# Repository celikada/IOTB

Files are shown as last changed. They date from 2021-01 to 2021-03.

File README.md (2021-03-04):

# IOTB
### Internet of Things Device
#### Version 3.0: 2021-1-17 [Wiki](https://github.com/celikada/IOTB/wiki)

#### Get expedited support or integration consultation for IOTB [from IOTECH](http://iotech.com.tr/)

IOTECH (http://iotech.com.tr)
---

IOTECH (http://iotech.com.tr)
### OVERVIEW:
IOTB is an internet of things edge device implementation. The hardware has digital inputs and outputs and offers connectivity for analog sensors and extensions.
It has open source firmware and upload ready various tcp/ip connection options according to needs.

**It is a platform**

IOTB is a platform that users can create and upload a firmware which they needed. 

**Main features:**
1. 100Mb Ethernet.
2. TTL Serial connection.
3. 8 Digital Inputs.
4. 8 Digital Outputs.
5. 5V-26V operational power range.
6. Opto isolation for IO.
7. 2 line (4+4) Isolated input voltage. 
8. Isolaated Output voltage.
9. Current protection for outputs.
10. Voltage progection for outputs.

IOTECH (http://iotech.com.tr)
IOTECH (http://iotech.com.tr)
IOTECH (http://iotech.com.tr)

STM32 architectute. Modbus and MQTT ready software.

### Changelog is located [here.](https://github.com/celikada/IOTB/wiki/Changelog)

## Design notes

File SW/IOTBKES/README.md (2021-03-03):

### IOTB Plant Firmware
 Various sensors and IO implementation for plants growing and ThingSpeak comminication.

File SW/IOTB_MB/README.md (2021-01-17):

# IOTB MODBUS
### IOTB Modbus Communication Software
#### Version 3.0: 2021-1-17 [Wiki](https://github.com/celikada/IOTB/wiki)

#### Get expedited support or integration consultation for IOTB [from IOTECH](http://iotech.com.tr/)

IOTECH (http://iotech.com.tr)
---

### OVERVIEW:
IOTB is an internet of things edge device implementation. The hardware has digital inputs and outputs and offers connectivity for analog sensors and extensions.
It has open source firmware and upload ready various tcp/ip connection options according to needs.

#### Register Address ####

**Holding Register**

1. Status
2. Version
3. SerialNum
4. IP1
5. IP2
6. IP3
7. IP4
8. MASK1
9. MASK2
10. MASK3
11. MASK4
12. GW1
13. GW2
14. GW3
15. GW4
16. DNS1
17. DNS2
18. DNS3
19. DNS4
20. IPS1
21. IPS2
22. IPS3
23. IPS4
24. CommPortH
25. CommPortL
26. VolatileOut
27. Reset

**Input Registers**

1. IN1
2. IN2
3. IN3
4. IN4
5. IN5
6. IN6
7. IN7
8. IN8
9. OUTPUTS
10. sht31 Temp
11. sht31 Hum
12. Board Temp
13. reserved
14. reserved

**Coil Registers**

1. OUT1
2. OUT2
3. OUT3
4. OUT4
5. OUT5
6. OUT6
7. OUT7
8. OUT8

Changelog is located here.

### Changelog is located [here.](https://github.com/celikada/IOTB/wiki/Changelog)

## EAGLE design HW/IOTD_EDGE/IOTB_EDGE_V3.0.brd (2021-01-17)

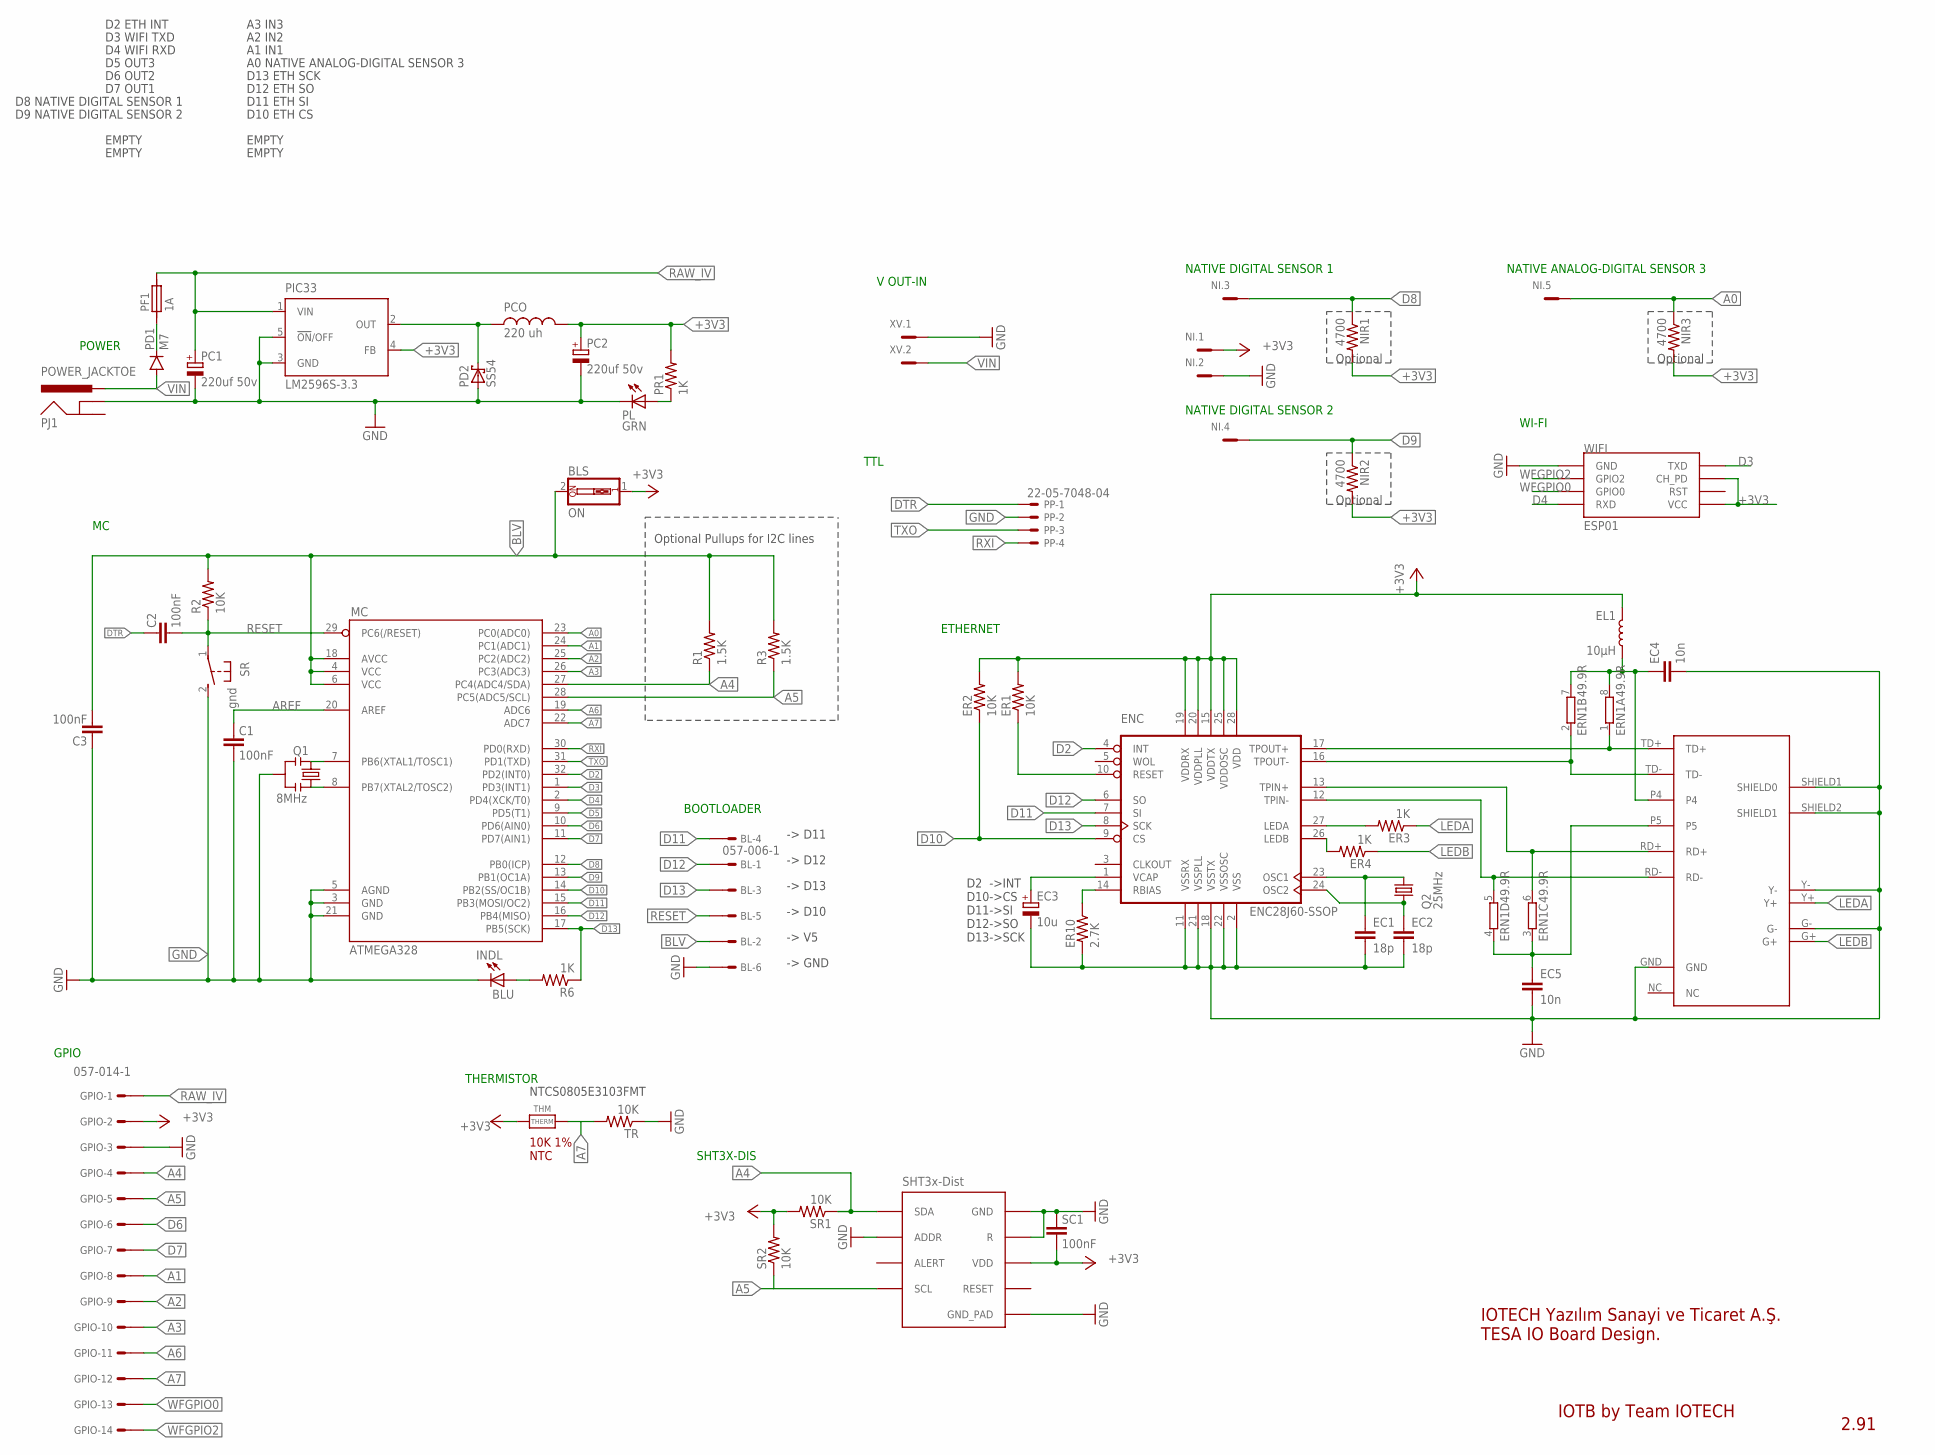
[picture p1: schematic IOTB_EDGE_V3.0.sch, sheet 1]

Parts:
BL: 057-006-1
BLS: ON; EDG-01
C1, C2, C3: 100nF; 0805
EC1, EC2: 18p; 0805
EC3: 10u; CT3216
EC4, EC5: 10n; 0805
EL1: 10µH; 0805
ENC: ENC28J60-SSOP; SSOP28
ER1, ER2: 10K; 0805
ER3, ER4: 1K; 0805
ER10: 2.7K; 0805
ERN1: 49.9R; 0603-ARV
ETHSOC: HR911105A; RJ45
GPIO: 057-014-1
INDL: BLU; CHIP-LED0805
MC: ATMEGA328; TQFP32-08
NI: MC5
NIR1, NIR2, NIR3: 4700; 0805
PC1, PC2: 220uf 50v; 140CLH-1010
PCO: 220 uh; MSS1260
PD1: M7; SMA-DIODE
PD2: SS54; SMB
PF1: 1A; 1820
PIC33: LM2596S-3.3; TO263-5
PJ1: POWER_JACKTOE; POWER_JACK_SMD_OVERPASTE_TOE
PL: GRN; CHIP-LED0805
PP: 22-05-7048-04; 7395-04
PR1: 1K; 0805
Q1: 8MHz; RESONATOR-SMD-1:1
Q2: 25MHz; 5.0X3.2_2
R1, R3: 1.5K; 0805
R2: 10K; 0805
R6: 1K; 0805
SC1: 100nF; 0805
SHT: SHT3X
SR: gnd; B3F-31XX
SR1, SR2: 10K; 0805
THM: THERM; MICROBUILDER_0805_NOTHERMALS
TR: 10K; 0805
WIFI: ESP01
XV: MC2

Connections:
+3V3: BLS.1, EL1.1, ENC.15 (VDDTX), ENC.19 (VDDRX), ENC.20 (VDDPLL), ENC.25 (VDDOSC), ENC.28 (VDD), ER1.2, ER2.2, GPIO.2, NI.1, NIR1.2, NIR2.2, NIR3.2, PC2.+, PCO.P$1, PIC33.4 (FB), PR1.2, SC1.1, SHT.VDD, SR1.2, SR2.2, THM.1, WIFI.CH_PD, WIFI.VCC; also elsewhere on the board
A0: MC.23 (PC0(ADC0)), NI.5, NIR3.1
A1: GPIO.8, MC.24 (PC1(ADC1))
A2: GPIO.9, MC.25 (PC2(ADC2))
A3: GPIO.10, MC.26 (PC3(ADC3))
A4: GPIO.4, MC.27 (PC4(ADC4/SDA)), R1.1, SHT.SDA, SR1.1; also elsewhere on the board
A5: GPIO.5, MC.28 (PC5(ADC5/SCL)), R3.1, SHT.SCL, SR2.1; also elsewhere on the board
A6: GPIO.11, MC.19 (ADC6)
A7: GPIO.12, MC.22 (ADC7), THM.2, TR.2
AREF: C1.2, MC.20 (AREF)
BLV: BL.2, BLS.2, C3.1, MC.4 (VCC), MC.6 (VCC), MC.18 (AVCC), R1.2, R2.2, R3.2
D2: ENC.4 (INT), MC.32 (PD2(INT0))
D3: MC.1 (PD3(INT1)), WIFI.TX (TXD)
D4: MC.2 (PD4(XCK/T0)), WIFI.RX (RXD)
D5: MC.9 (PD5(T1)); also elsewhere on the board
D6: GPIO.6, MC.10 (PD6(AIN0))
D7: GPIO.7, MC.11 (PD7(AIN1))
D8: MC.12 (PB0(ICP)), NI.3, NIR1.1
D9: MC.13 (PB1(OC1A)), NI.4, NIR2.1
D10: ENC.9 (CS), ER2.1, MC.14 (PB2(SS/OC1B))
D11: BL.4, ENC.7 (SI), MC.15 (PB3(MOSI/OC2))
D12: BL.1, ENC.6 (SO), MC.16 (PB4(MISO))
D13: BL.3, ENC.8 (SCK), MC.17 (PB5(SCK)), R6.1
DTR: C2.2, PP.1
EP4: EC4.1, EL1.2, ERN1.7 (2), ERN1.8 (2), ETHSOC.P4
EP5: EC5.1, ERN1.3 (1), ERN1.4 (1), ETHSOC.P5
GND: BL.6, C1.1, C3.2, EC1.2, EC2.2, EC3.-, EC4.2, EC5.2, ENC.2 (VSS), ENC.11 (VSSRX), ENC.18 (VSSTX), ENC.21 (VSSPLL), ENC.22 (VSSOSC), ER10.2, ETHSOC.G-, ETHSOC.GND, ETHSOC.SHIELD1 (SHIELD0), ETHSOC.SHIELD2 (SHIELD1), ETHSOC.Y-, GPIO.3, INDL.C, MC.3 (GND), MC.5 (AGND), MC.21 (GND), NI.2, PC1.-, PC2.-, PD2.A, PIC33.3 (GND), PIC33.5 (!ON!/OFF), PJ1.GND (GNDBREAK), PL.C, PP.2, Q1.2, SC1.2, SHT.ADDR, SHT.GND, SHT.GND_PAD, SHT.R, SR.2 (S), TR.1, WIFI.GND, XV.1; also elsewhere on the board
LEDA: ER3.1, ETHSOC.Y+
LEDB: ER4.1, ETHSOC.G+
unnamed: PD1.C, PF1.1
unnamed: INDL.A, R6.2
unnamed: ENC.27 (LEDA), ER3.2
unnamed: MC.8 (PB7(XTAL2/TOSC2)), Q1.3
unnamed: PL.A, PR1.1
unnamed: EC3.+, ENC.1 (VCAP)
unnamed: ENC.26 (LEDB), ER4.2
unnamed: MC.7 (PB6(XTAL1/TOSC1)), Q1.1
unnamed: PCO.P$2, PD2.C, PIC33.2 (OUT)
unnamed: ENC.10 (RESET), ER1.1
unnamed: ENC.14 (RBIAS), ER10.1
unnamed: EC2.1, ENC.24 (OSC2), Q2.1
unnamed: EC1.1, ENC.23 (OSC1), Q2.2
RAW_IV: GPIO.1, PC1.+, PF1.2, PIC33.1 (VIN)
RD+: ENC.13 (TPIN+), ERN1.6 (2), ETHSOC.RD+
RD-: ENC.12 (TPIN-), ERN1.5 (2), ETHSOC.RD-
RESET: BL.5, C2.1, MC.29 (PC6(/RESET)), R2.1, SR.1
RXI: MC.30 (PD0(RXD)), PP.4
TD+: ENC.17 (TPOUT+), ERN1.1, ETHSOC.TD+
TD-: ENC.16 (TPOUT-), ERN1.2 (1), ETHSOC.TD-
TXO: MC.31 (PD1(TXD)), PP.3
VIN: PD1.A, PJ1.VIN0 (PWR), XV.2
WFGPIO0: GPIO.13, WIFI.GPIO0
WFGPIO2: GPIO.14, WIFI.GPIO2

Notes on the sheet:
POWER
NATIVE DIGITAL SENSOR 1
NATIVE DIGITAL SENSOR 2
WI-FI
NATIVE ANALOG-DIGITAL SENSOR 3
IOTB by Team IOTECH
2.91
ETHERNET
D2 ->INT D10->CS D11->SI D12->SO D13->SCK
TTL
IOTECH Yazılım Sanayi ve Ticaret A.Ş. TESA IO Board Design.
Optional Pullups for I2C lines
D2 ETH INT
D8 NATIVE DIGITAL SENSOR 1
D9 NATIVE DIGITAL SENSOR 2
EMPTY
A3 IN3
A2 IN2
A1 IN1
A0 NATIVE ANALOG-DIGITAL SENSOR 3
D13 ETH SCK
D12 ETH SO
D11 ETH SI
D10 ETH CS
D4 WIFI RXD
D3 WIFI TXD
D7 OUT1
D6 OUT2
D5 OUT3
BOOTLOADER
-> D11
-> D12
-> D13
-> D10
-> V5
-> GND
Optional
V OUT-IN
GPIO
NTCS0805E3103FMT

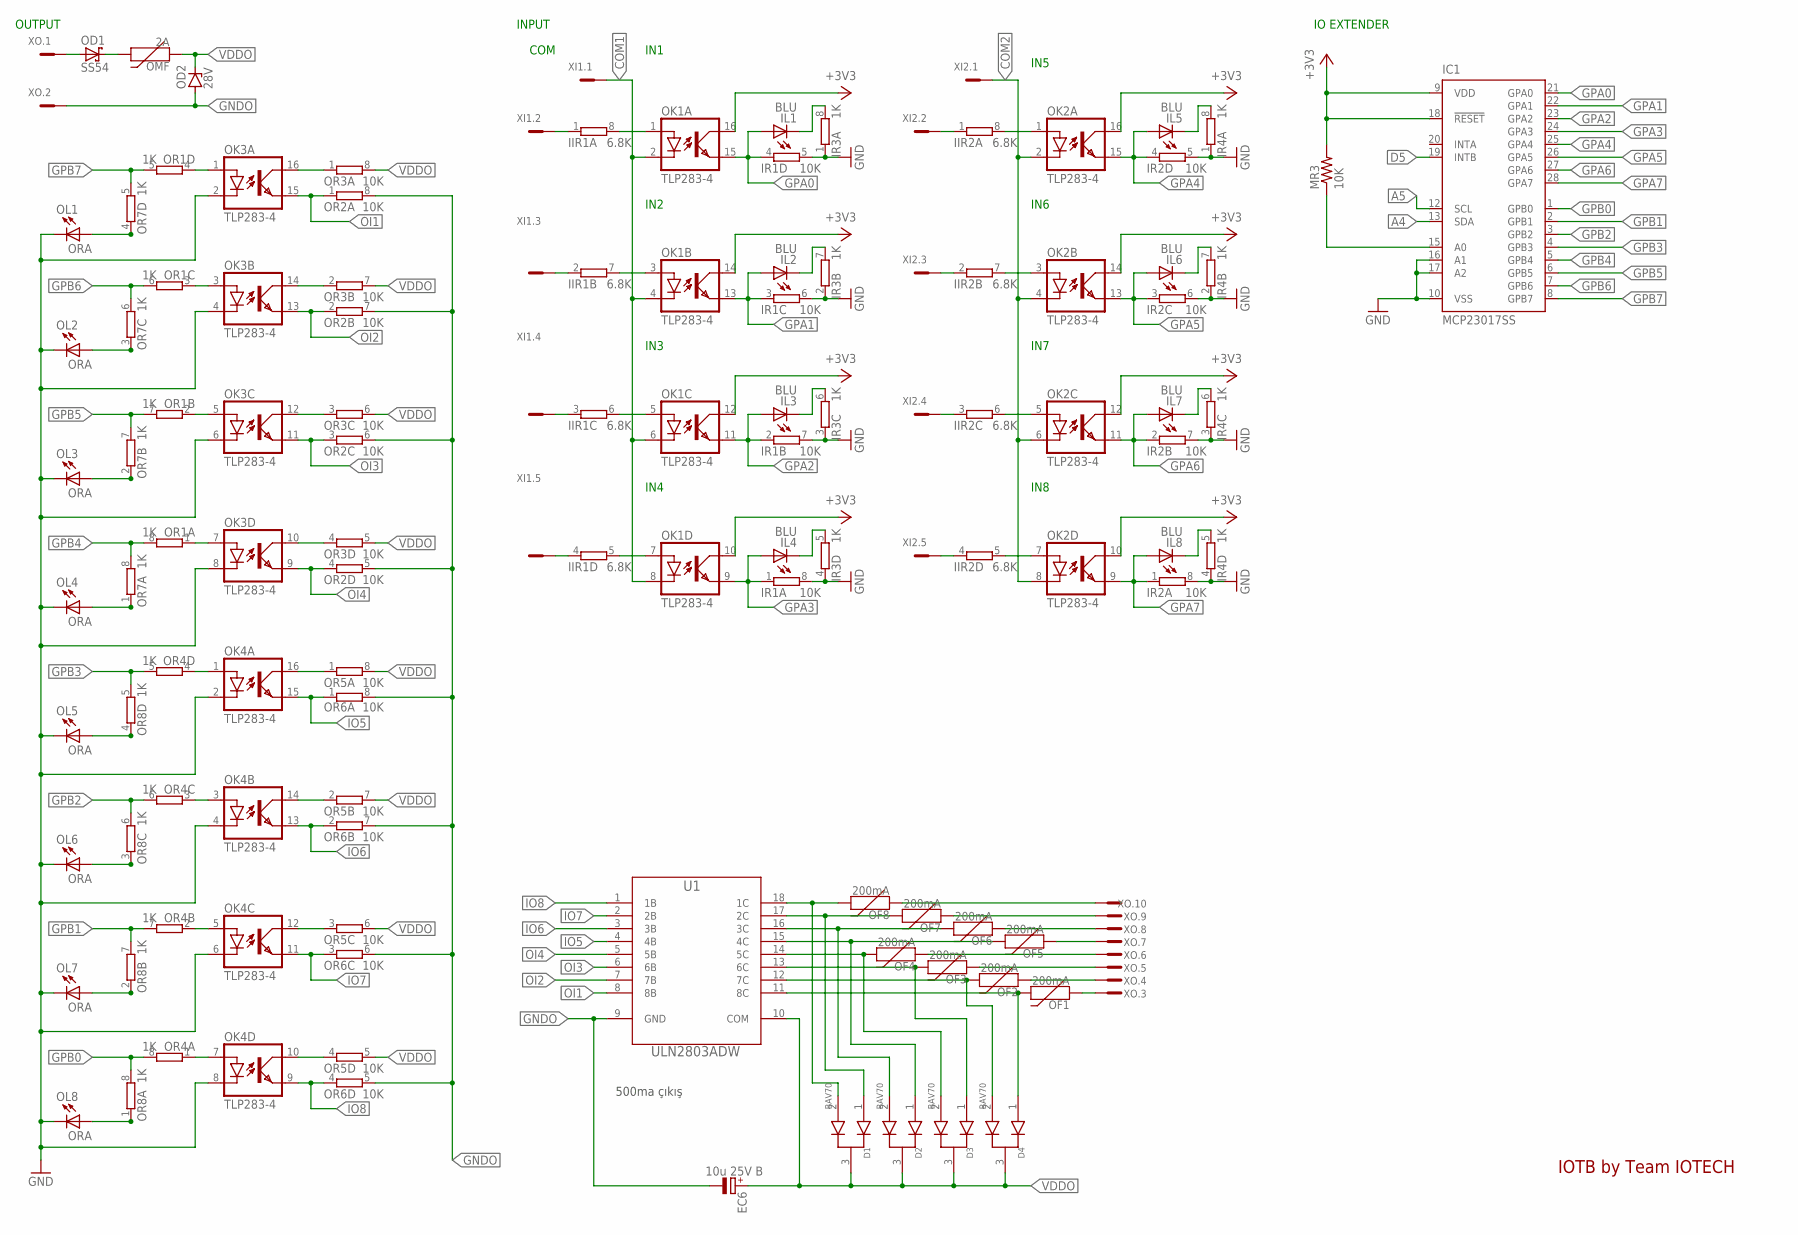
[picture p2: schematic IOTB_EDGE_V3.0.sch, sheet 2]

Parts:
D1, D2, D3, D4: BAV70; SOT-23-3
EC6: 10u 25V B; SMC_B
IC1: MCP23017SS; SSOP28
IIR1, IIR2: 6.8K; 0603-ARV
IL1, IL2, IL3, IL4, IL5, IL6, IL7, IL8: BLU; CHIP-LED0805
IR1, IR2: 10K; 0603-ARV
IR3, IR4: 1K; 0603-ARV
MR3: 10K; 0805
OD1: SS54; SMB
OD2: 28V; SMB
OF1, OF2, OF3, OF4, OF5, OF6, OF7, OF8: 200mA; 1206
OK1, OK2, OK3, OK4: TLP283-4; MINI-FLAT-16
OL1, OL2, OL3, OL4, OL5, OL6, OL7, OL8: ORA; CHIP-LED0805
OMF: 2A; 1206
OR1, OR4, OR7, OR8: 1K; 0603-ARV
OR2, OR3, OR5, OR6: 10K; 0603-ARV
U1: ULN2803ADW; SOIC127P1030X265-18N
XI1, XI2: MC5
XO: MC10

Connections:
+3V3: IC1.9 (VDD), IC1.18 (!RESET), MR3.2, OK1.10 (COL), OK1.12 (COL), OK1.14 (COL), OK1.16 (COL), OK2.10 (COL), OK2.12 (COL), OK2.14 (COL), OK2.16 (COL); also elsewhere on the board
A4: IC1.13 (SDA); also elsewhere on the board
A5: IC1.12 (SCL); also elsewhere on the board
COM1: OK1.2 (C), OK1.4 (C), OK1.6 (C), OK1.8 (C), XI1.1
COM2: OK2.2 (C), OK2.4 (C), OK2.6 (C), OK2.8 (C), XI2.1
D5: IC1.19 (INTB); also elsewhere on the board
GND: IC1.10 (VSS), IC1.16 (A1), IC1.17 (A2), IR1.5 (2), IR1.6 (2), IR1.7 (2), IR1.8 (2), IR2.5 (2), IR2.6 (2), IR2.7 (2), IR2.8 (2), IR3.1, IR3.2 (1), IR3.3 (1), IR3.4 (1), IR4.1, IR4.2 (1), IR4.3 (1), IR4.4 (1), OK3.2 (C), OK3.4 (C), OK3.6 (C), OK3.8 (C), OK4.2 (C), OK4.4 (C), OK4.6 (C), OK4.8 (C), OL1.C, OL2.C, OL3.C, OL4.C, OL5.C, OL6.C, OL7.C, OL8.C; also elsewhere on the board
GNDO: EC6.-, OD2.A, OR2.5 (2), OR2.6 (2), OR2.7 (2), OR2.8 (2), OR6.5 (2), OR6.6 (2), OR6.7 (2), OR6.8 (2), U1.9 (GND), XO.2
GPA0: IC1.21 (GPA0), IL1.A, IR1.4 (1), OK1.15 (EMIT)
GPA1: IC1.22 (GPA1), IL2.A, IR1.3 (1), OK1.13 (EMIT)
GPA2: IC1.23 (GPA2), IL3.A, IR1.2 (1), OK1.11 (EMIT)
GPA3: IC1.24 (GPA3), IL4.A, IR1.1, OK1.9 (EMIT)
GPA4: IC1.25 (GPA4), IL5.A, IR2.4 (1), OK2.15 (EMIT)
GPA5: IC1.26 (GPA5), IL6.A, IR2.3 (1), OK2.13 (EMIT)
GPA6: IC1.27 (GPA6), IL7.A, IR2.2 (1), OK2.11 (EMIT)
GPA7: IC1.28 (GPA7), IL8.A, IR2.1, OK2.9 (EMIT)
GPB0: IC1.1 (GPB0), OR4.8 (2), OR8.8 (2)
GPB1: IC1.2 (GPB1), OR4.7 (2), OR8.7 (2)
GPB2: IC1.3 (GPB2), OR4.6 (2), OR8.6 (2)
GPB3: IC1.4 (GPB3), OR4.5 (2), OR8.5 (2)
GPB4: IC1.5 (GPB4), OR1.8 (2), OR7.8 (2)
GPB5: IC1.6 (GPB5), OR1.7 (2), OR7.7 (2)
GPB6: IC1.7 (GPB6), OR1.6 (2), OR7.6 (2)
GPB7: IC1.8 (GPB7), OR1.5 (2), OR7.5 (2)
IO5: OK4.15 (EMIT), OR6.1, U1.4 (4B)
IO6: OK4.13 (EMIT), OR6.2 (1), U1.3 (3B)
IO7: OK4.11 (EMIT), OR6.3 (1), U1.2 (2B)
IO8: OK4.9 (EMIT), OR6.4 (1), U1.1 (1B)
unnamed: OD1.A, XO.1
unnamed: IC1.15 (A0), MR3.1
unnamed: OD1.C, OMF.2
unnamed: OF8.1, XO.10
unnamed: D1.1, OF7.2, U1.17 (2C)
unnamed: OK3.1 (A), OR1.4 (1)
unnamed: IL1.C, IR3.8 (2)
unnamed: IIR1.1, XI1.2
unnamed: IL2.C, IR3.7 (2)
unnamed: IL3.C, IR3.6 (2)
unnamed: IL4.C, IR3.5 (2)
unnamed: IL5.C, IR4.8 (2)
unnamed: IL6.C, IR4.7 (2)
unnamed: IL7.C, IR4.6 (2)
unnamed: IIR1.2 (1), XI1.3
unnamed: IIR1.8 (2), OK1.1 (A)
unnamed: IIR1.7 (2), OK1.3 (A)
unnamed: IIR1.6 (2), OK1.5 (A)
unnamed: IIR1.5 (2), OK1.7 (A)
unnamed: IIR1.3 (1), XI1.4
unnamed: IIR1.4 (1), XI1.5
unnamed: OK3.3 (A), OR1.3 (1)
unnamed: IIR2.1, XI2.2
unnamed: IIR2.8 (2), OK2.1 (A)
unnamed: IIR2.2 (1), XI2.3
unnamed: IIR2.7 (2), OK2.3 (A)
unnamed: IIR2.3 (1), XI2.4
unnamed: IIR2.6 (2), OK2.5 (A)
unnamed: IIR2.4 (1), XI2.5
unnamed: IIR2.5 (2), OK2.7 (A)
unnamed: IL8.C, IR4.5 (2)
unnamed: OK3.5 (A), OR1.2 (1)
unnamed: OK3.7 (A), OR1.1
unnamed: D1.2, OF8.2, U1.18 (1C)
unnamed: OK3.16 (COL), OR3.1
unnamed: D2.2, OF6.2, U1.16 (3C)
unnamed: D2.1, OF5.2, U1.15 (4C)
unnamed: OF7.1, XO.9
unnamed: OF6.1, XO.8
unnamed: OK3.14 (COL), OR3.2 (1)
unnamed: OF5.1, XO.7
unnamed: OF4.1, XO.6
unnamed: OK3.12 (COL), OR3.3 (1)
unnamed: D3.1, OF3.2, U1.13 (6C)
unnamed: OK3.10 (COL), OR3.4 (1)
unnamed: D4.2, OF2.2, U1.12 (7C)
unnamed: OL1.A, OR7.4 (1)
unnamed: OL2.A, OR7.3 (1)
unnamed: OL3.A, OR7.2 (1)
unnamed: OL4.A, OR7.1
unnamed: D4.1, OF1.2, U1.11 (8C)
unnamed: D3.2, OF4.2, U1.14 (5C)
unnamed: OF3.1, XO.5
unnamed: OF2.1, XO.4
unnamed: OF1.1, XO.3
unnamed: OK4.1 (A), OR4.4 (1)
unnamed: OK4.3 (A), OR4.3 (1)
unnamed: OK4.5 (A), OR4.2 (1)
unnamed: OK4.7 (A), OR4.1
unnamed: OK4.16 (COL), OR5.1
unnamed: OK4.14 (COL), OR5.2 (1)
unnamed: OK4.12 (COL), OR5.3 (1)
unnamed: OK4.10 (COL), OR5.4 (1)
unnamed: OL5.A, OR8.4 (1)
unnamed: OL6.A, OR8.3 (1)
unnamed: OL7.A, OR8.2 (1)
unnamed: OL8.A, OR8.1
OI1: OK3.15 (EMIT), OR2.1, U1.8 (8B)
OI2: OK3.13 (EMIT), OR2.2 (1), U1.7 (7B)
OI3: OK3.11 (EMIT), OR2.3 (1), U1.6 (6B)
OI4: OK3.9 (EMIT), OR2.4 (1), U1.5 (5B)
VDDO: D1.3, D2.3, D3.3, D4.3, EC6.+, OD2.C, OMF.1, OR3.5 (2), OR3.6 (2), OR3.7 (2), OR3.8 (2), OR5.5 (2), OR5.6 (2), OR5.7 (2), OR5.8 (2), U1.10 (COM)

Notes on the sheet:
IOTB by Team IOTECH
INPUT
IN1
IN2
IN3
IN4
IN5
IN6
IN7
IN8
COM
OUTPUT
IO EXTENDER
500ma çıkış

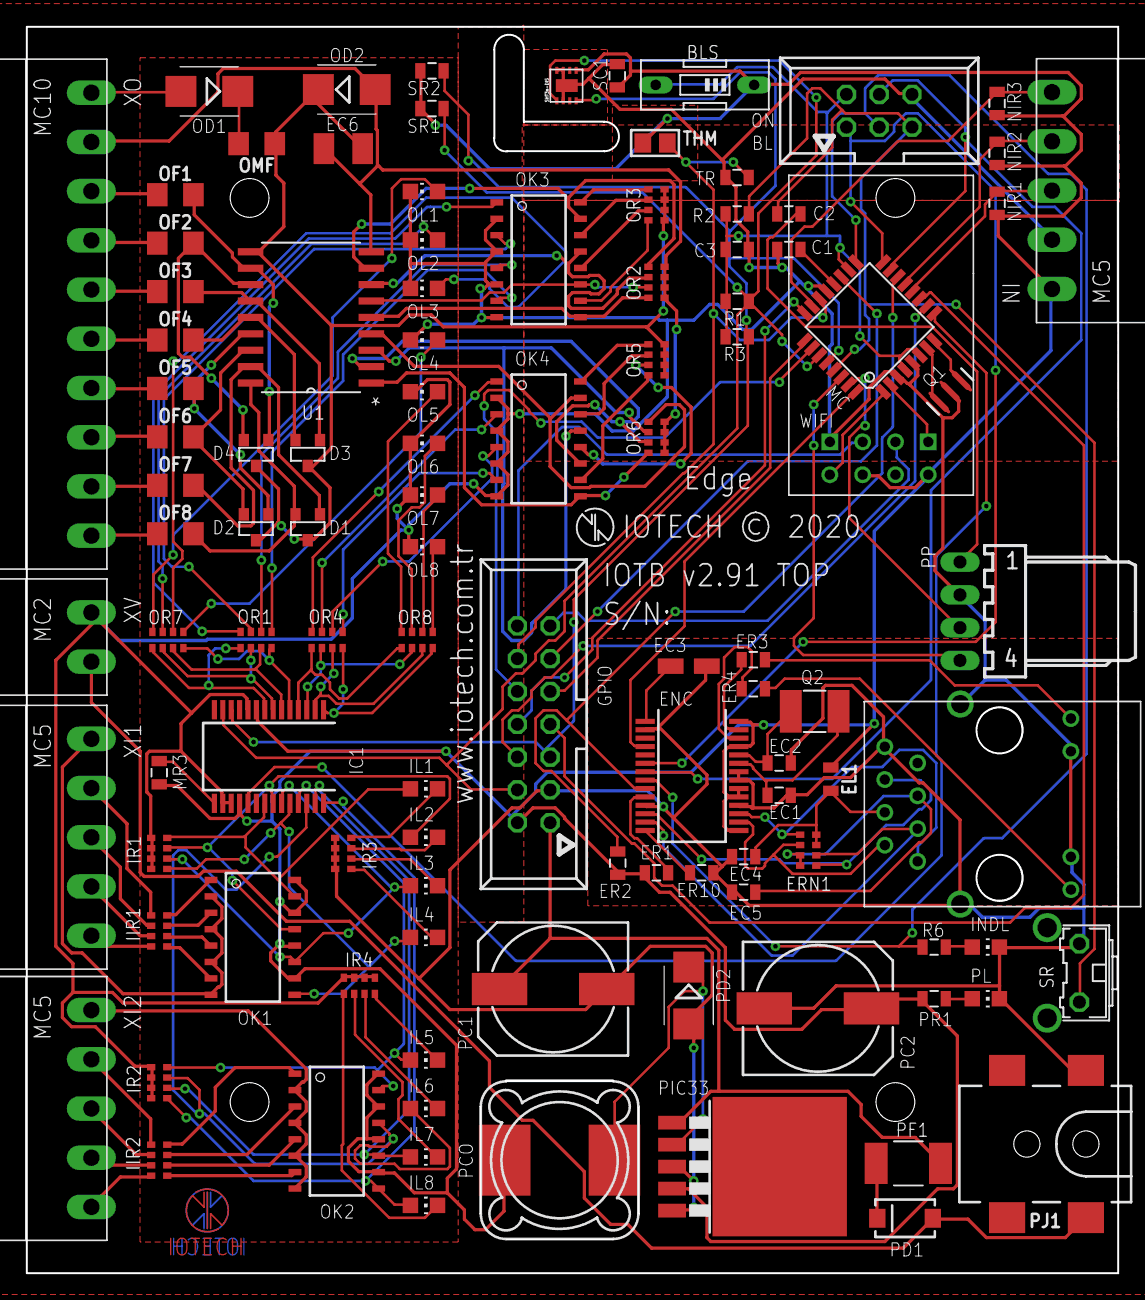
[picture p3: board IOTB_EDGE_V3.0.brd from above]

Board: 2 copper layers, 84.5 x 96.5 mm, 110 parts (1 on the bottom side), 148 nets.

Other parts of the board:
LOGOB: IOTECH_COPPER_W_TEXT
LOGOT: IOTECH_COPPER_W_TEXT

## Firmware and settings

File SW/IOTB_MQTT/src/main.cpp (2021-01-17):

/*                                                                                                                                                                                                      
        Name:       IOTB Modbus                                                                                                                                                                      
        Created:    17/1/2021 2:17:06 PM                                                                                                                                                             
        Author:     Ozan Celikada                                                                                                                                                            
*/

#include <Wire.h>
#include <SPI.h>
#include <Ethernet2.h> 

#include <ArduinoRS485.h> // ArduinoModbus depends on the ArduinoRS485 library
#include <ArduinoModbus.h>

#include <IOTBConf.h>
#include <Adafruit_MCP23017.h>
#include <Adafruit_SHT31.h>
#include <SoftwareSerial.h>

int keyIndex = 0;                 // your network key Index number (needed only for WEP)

const int ledPin = LED_BUILTIN;

EthernetServer ethenet_server = EthernetServer(502);
ModbusTCPServer modbusTCPServer;

//Wifi to serial
SoftwareSerial espLine(4, 3); // RX, TX


//NATIVE SENSOR INPUT
constexpr auto  NIT1 = 8; // DHT Sensor
constexpr auto  NIT2 = 9;
constexpr auto  NIT3 = A0;

//INPUTS
constexpr auto PI1 = 0;//Door1 ;
constexpr auto PI2 = 1; //Door2;
constexpr auto PI3 = 2; //leakSensor
constexpr auto PI4 = 3; //
constexpr auto PI5 = 4;//
constexpr auto PI6 = 5; //
constexpr auto PI7 = 6; //
constexpr auto PI8 = 7; //

//OUTPUTS
constexpr auto PQ1 = 8 ;
constexpr auto PQ2 = 9 ;
constexpr auto PQ3 = 10; 
constexpr auto PQ4 = 11;
constexpr auto PQ5 = 12;
constexpr auto PQ6 = 13;
constexpr auto PQ7 = 14;
constexpr auto PQ8 = 15;

//Devices
Adafruit_SHT31 sht31 = Adafruit_SHT31();
Adafruit_MCP23017 mcp;

//Conf
IOTBConfClass* IOTBConfC = IOTBConfClass::getInstance();

void serialInit();
void confInit();
void ethernetInit();
void modbusInit();
void mcpInit();
void shtInit();

void readCoilRegsToOutputs();
void readInputsToInputReg();
void readHoldingRegsToConfig();
int readCardTHM();




void setup() {
	pinMode(PC13, OUTPUT);  
	digitalWrite(PC13, HIGH);   // turn the LED on (HIGH is the voltage level)                                                                                                                            
  	delay(500);              // wait for a second                                                                                                                                                         
  	digitalWrite(PC13, LOW);    // turn the LED off by making the voltage LOW                                                                                                                             
  	delay(500);              // wait for a second          
	digitalWrite(PC13, HIGH);   // turn the LED on (HIGH is the voltage level)                                                                                                                            
  	delay(500);              // wait for a second                                                                                                                                                         
  	digitalWrite(PC13, LOW);    // turn the LED off by making the voltage LOW                                                                                                                             
  	delay(500);              // wait for a second          
	digitalWrite(PC13, HIGH);   // turn the LED on (HIGH is the voltage level)                                                                                                                            
  	delay(500);              // wait for a second                                                                                                                                                         
  	digitalWrite(PC13, LOW);    // turn the LED off by making the voltage LOW                                                                                                                             
  	delay(500);              // wait for a second          




	//serialInit();//portlar yanlış olabilir çakılıyor
	confInit();
  	ethernetInit();
	modbusInit();
	mcpInit();
	shtInit();
	//volatilityInit();
}

void loop() {
  	// listen for incoming clients
  	EthernetClient client = ethenet_server.available();
  
  	if (client) {
    // a new client connected
    // let the Modbus TCP accept the connection 
    	modbusTCPServer.accept(client);

    	while (client.connected()) {
      	// poll for Modbus TCP requests, while client connected
      	modbusTCPServer.poll();
		//update IO and others
		readCoilRegsToOutputs();
		readInputsToInputReg();
		readHoldingRegsToConfig();
    }
  }
}

//------------------------------------------------------
void serialInit()
{
	Serial.begin(9600);
	espLine.begin(115200);
}

void shtInit()
{
	sht31.begin(0x44);
}

void mcpInit()
{
	mcp.begin(1);      // Default device address 0
    //mcp.begin(0x21);      // Default device address 0

	mcp.pinMode(PI1, INPUT);
	mcp.pinMode(PI2, INPUT);
	mcp.pinMode(PI3, INPUT);
	mcp.pinMode(PI4, INPUT);
	mcp.pinMode(PI5, INPUT);
	mcp.pinMode(PI6, INPUT);
	mcp.pinMode(PI7, INPUT);
	mcp.pinMode(PI8, INPUT);

	// mcp.pullUp(PI1, HIGH);     // Puled high to ~100k
	// mcp.pullUp(PI2, HIGH);     // Puled high to ~100k
	// mcp.pullUp(PI3, HIGH);     // Puled high to ~100k
	// mcp.pullUp(PI4, HIGH);     // Puled high to ~100k
	// mcp.pullUp(PI5, HIGH);     // Puled high to ~100k
	// mcp.pullUp(PI6, HIGH);     // Puled high to ~100k
	// mcp.pullUp(PI7, HIGH);     // Puled high to ~100k
	// mcp.pullUp(PI8, HIGH);     // Puled high to ~100k

	mcp.pinMode(PQ1, OUTPUT);     // LED output
	mcp.pinMode(PQ2, OUTPUT);     // LED output
	mcp.pinMode(PQ3, OUTPUT);     // LED output
	mcp.pinMode(PQ4, OUTPUT);     // LED output
	mcp.pinMode(PQ5, OUTPUT);     // LED output
	mcp.pinMode(PQ6, OUTPUT);     // LED output
	mcp.pinMode(PQ7, OUTPUT);     // LED output
	mcp.pinMode(PQ8, OUTPUT);     // LED output

	// for (int i = 8; i < 16; i++)
	// {
	// 	mcp.digitalWrite(i, LOW);
	// }
}

void confInit()
{
	IOTBConfC->read();
	if(IOTBConfC->IOTBConf.Status != 1)
	{
		IOTBConfC->init();
	}
}

void ethernetInit()
{
  
	byte mac[] = { 0xDE, 0xED, 0xBA, 0xFE, 0xFE, 0xED };
	mac[5] = IOTBConfC->IOTBConf.SerialNum;

	IPAddress ip = IPAddress(IOTBConfC->IOTBConf.IP1, IOTBConfC->IOTBConf.IP2, IOTBConfC->IOTBConf.IP3, IOTBConfC->IOTBConf.IP4);
	IPAddress dns = IPAddress(IOTBConfC->IOTBConf.DNS1, IOTBConfC->IOTBConf.DNS2, IOTBConfC->IOTBConf.DNS3, IOTBConfC->IOTBConf.DNS4);
	IPAddress gateway = IPAddress(IOTBConfC->IOTBConf.GW1, IOTBConfC->IOTBConf.GW2, IOTBConfC->IOTBConf.GW3, IOTBConfC->IOTBConf.GW4);
	IPAddress subnet = IPAddress(IOTBConfC->IOTBConf.MASK1, IOTBConfC->IOTBConf.MASK2, IOTBConfC->IOTBConf.MASK3, IOTBConfC->IOTBConf.MASK4);

	//Ethernet
  	Ethernet.init(PA4);
	Ethernet.begin(mac, ip, dns, gateway, subnet);
	//analogReference(DEFAULT);

  	int portNum = IOTBConfC->GetPort();
  	if(portNum != 502)
	{
		
	}
  	ethenet_server.begin();
}

void modbusInit()
{
  	// start the Modbus TCP server
  	if (!modbusTCPServer.begin()) {
  	  //Serial.println("Failed to start Modbus TCP Server!");
  	  while (1);
  	}

	//Configuration
  	modbusTCPServer.configureHoldingRegisters(0x00, 27);
  	modbusTCPServer.configureInputRegisters(0x00, 14);
  	modbusTCPServer.configureCoils(0x00, 8);

	//Holding
  	modbusTCPServer.holdingRegisterWrite(0, IOTBConfC->IOTBConf.Status);
  	modbusTCPServer.holdingRegisterWrite(1, IOTBConfC->IOTBConf.Version);
  	modbusTCPServer.holdingRegisterWrite(2, IOTBConfC->IOTBConf.SerialNum); 

  	modbusTCPServer.holdingRegisterWrite(3, IOTBConfC->IOTBConf.IP1);
  	modbusTCPServer.holdingRegisterWrite(4, IOTBConfC->IOTBConf.IP2);
  	modbusTCPServer.holdingRegisterWrite(5, IOTBConfC->IOTBConf.IP3);
  	modbusTCPServer.holdingRegisterWrite(6, IOTBConfC->IOTBConf.IP4);
	
  	modbusTCPServer.holdingRegisterWrite(7, IOTBConfC->IOTBConf.MASK1);
  	modbusTCPServer.holdingRegisterWrite(8, IOTBConfC->IOTBConf.MASK2);
  	modbusTCPServer.holdingRegisterWrite(9, IOTBConfC->IOTBConf.MASK3);
  	modbusTCPServer.holdingRegisterWrite(10, IOTBConfC->IOTBConf.MASK4);
	
  	modbusTCPServer.holdingRegisterWrite(11, IOTBConfC->IOTBConf.GW1);
  	modbusTCPServer.holdingRegisterWrite(12, IOTBConfC->IOTBConf.GW2);
  	modbusTCPServer.holdingRegisterWrite(13, IOTBConfC->IOTBConf.GW3);
  	modbusTCPServer.holdingRegisterWrite(14, IOTBConfC->IOTBConf.GW4);
	
  	modbusTCPServer.holdingRegisterWrite(15, IOTBConfC->IOTBConf.DNS1);
  	modbusTCPServer.holdingRegisterWrite(16, IOTBConfC->IOTBConf.DNS2);
  	modbusTCPServer.holdingRegisterWrite(17, IOTBConfC->IOTBConf.DNS3);
  	modbusTCPServer.holdingRegisterWrite(18, IOTBConfC->IOTBConf.DNS4);
	
  	modbusTCPServer.holdingRegisterWrite(19, IOTBConfC->IOTBConf.IPS1);
  	modbusTCPServer.holdingRegisterWrite(20, IOTBConfC->IOTBConf.IPS2);
  	modbusTCPServer.holdingRegisterWrite(21, IOTBConfC->IOTBConf.IPS3);
  	modbusTCPServer.holdingRegisterWrite(22, IOTBConfC->IOTBConf.IPS4);
	
  	modbusTCPServer.holdingRegisterWrite(23, IOTBConfC->IOTBConf.CommPortH); 
  	modbusTCPServer.holdingRegisterWrite(24, IOTBConfC->IOTBConf.CommPortL); 
	
  	modbusTCPServer.holdingRegisterWrite(25, IOTBConfC->IOTBConf.VolatileOut);
	
  	modbusTCPServer.holdingRegisterWrite(26, IOTBConfC->Reset);
}

//----------------------------------------------------------------------
void readCoilRegsToOutputs()
{
	mcp.digitalWrite(PQ1, modbusTCPServer.coilRead(0x00));
	mcp.digitalWrite(PQ2, modbusTCPServer.coilRead(0x01));
	mcp.digitalWrite(PQ3, modbusTCPServer.coilRead(0x02));
	mcp.digitalWrite(PQ4, modbusTCPServer.coilRead(0x03));
	mcp.digitalWrite(PQ5, modbusTCPServer.coilRead(0x04));
	mcp.digitalWrite(PQ6, modbusTCPServer.coilRead(0x05));
	mcp.digitalWrite(PQ7, modbusTCPServer.coilRead(0x06));
	mcp.digitalWrite(PQ8, modbusTCPServer.coilRead(0x07));
}

void readInputsToInputReg()
{	
	u_int8_t coils = modbusTCPServer.coilRead(0x00) & 0x0001;
	coils |= ((modbusTCPServer.coilRead(0x01) & 0x0001) << 1);
	coils |= ((modbusTCPServer.coilRead(0x02) & 0x0001) << 2);
	coils |= ((modbusTCPServer.coilRead(0x03) & 0x0001) << 3);
	coils |= ((modbusTCPServer.coilRead(0x04) & 0x0001) << 4);
	coils |= ((modbusTCPServer.coilRead(0x05) & 0x0001) << 5);
	coils |= ((modbusTCPServer.coilRead(0x06) & 0x0001) << 6);
	coils |= ((modbusTCPServer.coilRead(0x07) & 0x0001) << 7);

	modbusTCPServer.inputRegisterWrite(0, mcp.digitalRead(PI1));
	modbusTCPServer.inputRegisterWrite(1, mcp.digitalRead(PI2));
	modbusTCPServer.inputRegisterWrite(2, mcp.digitalRead(PI3));
	modbusTCPServer.inputRegisterWrite(3, mcp.digitalRead(PI4));
	modbusTCPServer.inputRegisterWrite(4, mcp.digitalRead(PI5));
	modbusTCPServer.inputRegisterWrite(5, mcp.digitalRead(PI6));
	modbusTCPServer.inputRegisterWrite(6, mcp.digitalRead(PI7));
	modbusTCPServer.inputRegisterWrite(7, mcp.digitalRead(PI8));

	modbusTCPServer.inputRegisterWrite(8, coils);
	
	modbusTCPServer.inputRegisterWrite(9, sht31.readTemperature());
	modbusTCPServer.inputRegisterWrite(10, sht31.readHumidity());

	modbusTCPServer.inputRegisterWrite(11, readCardTHM());
	//other inputs***********
	modbusTCPServer.inputRegisterWrite(12, 0);
	modbusTCPServer.inputRegisterWrite(13, 0);

}

void readHoldingRegsToConfig()
{
	if(modbusTCPServer.holdingRegisterRead(26) == 1)
	{
		IOTBConfC->IOTBConf.Status		= modbusTCPServer.holdingRegisterRead(0);
		IOTBConfC->IOTBConf.Version 	= modbusTCPServer.holdingRegisterRead(1);
		IOTBConfC->IOTBConf.SerialNum  	= modbusTCPServer.holdingRegisterRead(2);
		IOTBConfC->IOTBConf.IP1 		= modbusTCPServer.holdingRegisterRead(3);
		IOTBConfC->IOTBConf.IP2 		= modbusTCPServer.holdingRegisterRead(4);
		IOTBConfC->IOTBConf.IP3 		= modbusTCPServer.holdingRegisterRead(5);
		IOTBConfC->IOTBConf.IP4 		= modbusTCPServer.holdingRegisterRead(6);
		IOTBConfC->IOTBConf.MASK1 		= modbusTCPServer.holdingRegisterRead(7);
		IOTBConfC->IOTBConf.MASK2 		= modbusTCPServer.holdingRegisterRead(8);
		IOTBConfC->IOTBConf.MASK3 		= modbusTCPServer.holdingRegisterRead(9);
		IOTBConfC->IOTBConf.MASK4 		= modbusTCPServer.holdingRegisterRead(10);
		IOTBConfC->IOTBConf.GW1 		= modbusTCPServer.holdingRegisterRead(11);
		IOTBConfC->IOTBConf.GW2 		= modbusTCPServer.holdingRegisterRead(12);
		IOTBConfC->IOTBConf.GW3 		= modbusTCPServer.holdingRegisterRead(13);
		IOTBConfC->IOTBConf.GW4 		= modbusTCPServer.holdingRegisterRead(14);
		IOTBConfC->IOTBConf.DNS1 		= modbusTCPServer.holdingRegisterRead(15);
		IOTBConfC->IOTBConf.DNS2 		= modbusTCPServer.holdingRegisterRead(16);
		IOTBConfC->IOTBConf.DNS3 		= modbusTCPServer.holdingRegisterRead(17);
		IOTBConfC->IOTBConf.DNS4 		= modbusTCPServer.holdingRegisterRead(18);
		IOTBConfC->IOTBConf.IPS1 		= modbusTCPServer.holdingRegisterRead(19);
		IOTBConfC->IOTBConf.IPS2 		= modbusTCPServer.holdingRegisterRead(20);
		IOTBConfC->IOTBConf.IPS3 		= modbusTCPServer.holdingRegisterRead(21);
		IOTBConfC->IOTBConf.IPS4 		= modbusTCPServer.holdingRegisterRead(22);
		IOTBConfC->IOTBConf.CommPortH 	= modbusTCPServer.holdingRegisterRead(23);
		IOTBConfC->IOTBConf.CommPortL 	= modbusTCPServer.holdingRegisterRead(24);
		IOTBConfC->IOTBConf.VolatileOut = modbusTCPServer.holdingRegisterRead(25);
		IOTBConfC->Reset				= 0;
		IOTBConfC->save();
		NVIC_SystemReset();
	}
}

int readCardTHM()
{
	int Vo;
	float R1 = 10000;
	float logR2, R2, T;
	float c1 = 1.009249522e-03, c2 = 2.378405444e-04, c3 = 2.019202697e-07;


	Vo = analogRead(A7);
  	R2 = R1 * (1023.0 / (float)Vo - 1.0);
  	logR2 = log(R2);
  	T = (1.0 / (c1 + c2*logR2 + c3*logR2*logR2*logR2));
  	T = T - 273.15;
	return T;
}

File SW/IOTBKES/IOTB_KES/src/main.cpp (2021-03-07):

#include <Arduino.h>

#include <DHT.h>
#include <SoftwareSerial.h>
#include <Wire.h>
#include <Adafruit_MCP23017.h>
#include <OneWire.h>
#include <DallasTemperature.h>

#define sendinterval 300000

String inString = "";    // string to hold input
unsigned long lastSendToESP = 0;

//NATIVE SENSOR INPUT
constexpr auto  NIT1 = 8; // DHT Sensor
constexpr auto  NIT2 = 9; //DS18S20
constexpr auto  NIT3 = A0;//soil moisto

//INPUTS
constexpr auto PI1 = 0;//Door1 ;
constexpr auto PI2 = 1; //Door2;
constexpr auto PI3 = 2; //leakSensor
constexpr auto PI4 = 3; //
constexpr auto PI5 = 4;//
constexpr auto PI6 = 5; //
constexpr auto PI7 = 6; //
constexpr auto PI8 = 7; //

//OUTPUTS
constexpr auto PQ1 = 8 ;
constexpr auto PQ2 = 9 ;
constexpr auto PQ3 = 10; 
constexpr auto PQ4 = 11;
constexpr auto PQ5 = 12;
constexpr auto PQ6 = 13;
constexpr auto PQ7 = 14;
constexpr auto PQ8 = 15;

//components&sensors
DHT dht(NIT1, DHT22);
SoftwareSerial espLine(3, 4); // RX, TX
Adafruit_MCP23017 mcp;
// Setup a oneWire instance to communicate with any OneWire devices (not just Maxim/Dallas temperature ICs)
OneWire oneWire(NIT2);
// Pass our oneWire reference to Dallas Temperature. 
DallasTemperature sensors(&oneWire);

//GlobalVariable
float DHTTempVal = 0;
float DHTHumVal = 0;
int THMVal = 0;
uint8_t I1Val = 0;
uint8_t I2Val = 0;
uint8_t I3Val = 0;
uint8_t I4Val = 0;
uint8_t I5Val = 0;
uint8_t I6Val = 0;
uint8_t I7Val = 0;
uint8_t I8Val = 0;
int soilMoistureValue = 0;
int soilTempValue = 0;

//soil moisto cal const
const int AirValue = 880;   
const int WaterValue = 500;  
int soilmoisturepercent=0;
int intervals = (AirValue - WaterValue)/3;  
//
/*
const int AirValue = 600;   //you need to replace this value with Value_1
const int WaterValue = 350;  //you need to replace this value with Value_2
int soilMoistureValue = 0;
int soilmoisturepercent=0;
*/
//

void chkEspLine();

void initDHT();
void mcpInit();

void readDHT();
void ReadCardTHM();
void ReadDigiInputs();
void ReadDigiOutputs();
void readMoisto();
void readSoilTemp();

void SendToEsp();

void setup() {
  // put your setup code here, to run once:
  Serial.begin(9600);

  espLine.begin(9600);
  sensors.begin();
	initDHT();
  mcpInit();
  lastSendToESP = millis();
}

void loop() {
  // put your main code here, to run repeatedly:
  /*mcp.digitalWrite(PQ1,HIGH);
	mcp.digitalWrite(PQ2,HIGH);
	mcp.digitalWrite(PQ3,HIGH);
	mcp.digitalWrite(PQ4,HIGH);
	mcp.digitalWrite(PQ5,HIGH);
	mcp.digitalWrite(PQ6,HIGH);
	mcp.digitalWrite(PQ7,HIGH);
	mcp.digitalWrite(PQ8,HIGH);
	delay(1000);

	mcp.digitalWrite(PQ1,LOW);
	mcp.digitalWrite(PQ2,LOW);
	mcp.digitalWrite(PQ3,LOW);
	mcp.digitalWrite(PQ4,LOW);
	mcp.digitalWrite(PQ5,LOW);
	mcp.digitalWrite(PQ6,LOW);
	mcp.digitalWrite(PQ7,LOW);
	mcp.digitalWrite(PQ8,LOW);
	
	delay(1000);
*/
  chkEspLine();

	readDHT();
  ReadCardTHM();
  ReadDigiInputs();
  ReadDigiOutputs();
  readMoisto();
  readSoilTemp();

  long countdown = (sendinterval + lastSendToESP - millis())/1000;
  Serial.print("Countdown ");
  Serial.println(countdown);
  Serial.println("------------------------------");
  SendToEsp();
  delay(2000);
}

void chkEspLine()
{
  while (espLine.available() > 0) {
    int inChar = espLine.read();
    // convert the incoming byte to a char and add it to the string:
    inString += (char)inChar;
    
    // if you get a newline, print the string, then the string's value:
    if (inChar == '\n') {
      Serial.print("ESP LINE :");
      Serial.println(inString);
      // clear the string for new input:
      inString = "";
    }
  }
}

//------------------------------------------------------------------------
void initDHT()
{
  dht.begin();
}

void mcpInit()
{
	mcp.begin(1);      // Default device address 0
    //mcp.begin(0x21);      // Default device address 0

	mcp.pinMode(PI1, INPUT);
	mcp.pinMode(PI2, INPUT);
	mcp.pinMode(PI3, INPUT);
	mcp.pinMode(PI4, INPUT);
	mcp.pinMode(PI5, INPUT);
	mcp.pinMode(PI6, INPUT);
	mcp.pinMode(PI7, INPUT);
	mcp.pinMode(PI8, INPUT);

	mcp.pinMode(PQ1, OUTPUT);     // LED output
	mcp.pinMode(PQ2, OUTPUT);     // LED output
	mcp.pinMode(PQ3, OUTPUT);     // LED output
	mcp.pinMode(PQ4, OUTPUT);     // LED output
	mcp.pinMode(PQ5, OUTPUT);     // LED output
	mcp.pinMode(PQ6, OUTPUT);     // LED output
	mcp.pinMode(PQ7, OUTPUT);     // LED output
	mcp.pinMode(PQ8, OUTPUT);     // LED output
}

//------------------------------------------------------------------------
void readDHT()
{
  // Reading temperature or humidity takes about 250 milliseconds!
  // Sensor readings may also be up to 2 seconds 'old' (its a very slow sensor)
  float h = DHTHumVal = dht.readHumidity();
  // Read temperature as Celsius (the default)
  float t = DHTTempVal = dht.readTemperature();

  Serial.print(F("Humidity:         "));
  Serial.print(h);
  Serial.println(F("% "));
  Serial.print(F("Temperature:      "));
  Serial.print(t);
  Serial.println(F("°C "));

}
void ReadCardTHM()
{
	int Vo;
	float R1 = 10000;
	float logR2, R2, T;
	float c1 = 1.009249522e-03, c2 = 2.378405444e-04, c3 = 2.019202697e-07;


	Vo = analogRead(A7);
  	R2 = R1 * (1023.0 / (float)Vo - 1.0);
  	logR2 = log(R2);
  	T = (1.0 / (c1 + c2*logR2 + c3*logR2*logR2*logR2));
  	T = T - 273.15;

	THMVal = T;
  Serial.print(F("IOTB Temperature: "));
  Serial.print(T);
  Serial.println(F("°C "));
}

void ReadDigiInputs()
{
	I1Val = mcp.digitalRead(PI1);
	I2Val = mcp.digitalRead(PI2);
	I3Val = mcp.digitalRead(PI3);
	I4Val = mcp.digitalRead(PI4);
	I5Val = mcp.digitalRead(PI5);
	I6Val = mcp.digitalRead(PI6);
	I7Val = mcp.digitalRead(PI7);
	I8Val = mcp.digitalRead(PI8);

  Serial.print("INPUT PORTS:  [");
  Serial.print(I1Val);
  Serial.print(" ,");
  Serial.print(I2Val);
  Serial.print(" ,");
  Serial.print(I3Val);
  Serial.print(" ,");
  Serial.print(I4Val);
  Serial.print(" ,");
  Serial.print(I5Val);
  Serial.print(" ,");
  Serial.print(I6Val);
  Serial.print(" ,");
  Serial.print(I7Val);
  Serial.print(" ,");
  Serial.print(I8Val);
  Serial.println(" ]");
}

void ReadDigiOutputs()
{
  Serial.print("OUTPUT PORTS: [");
  Serial.print(mcp.digitalRead(PQ1));
  Serial.print(" ,");
  Serial.print(mcp.digitalRead(PQ2));
  Serial.print(" ,");
  Serial.print(mcp.digitalRead(PQ3));
  Serial.print(" ,");
  Serial.print(mcp.digitalRead(PQ4));
  Serial.print(" ,");
  Serial.print(mcp.digitalRead(PQ5));
  Serial.print(" ,");
  Serial.print(mcp.digitalRead(PQ6));
  Serial.print(" ,");
  Serial.print(mcp.digitalRead(PQ7));
  Serial.print(" ,");
  Serial.print(mcp.digitalRead(PQ8));
  Serial.println(" ]");
}
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

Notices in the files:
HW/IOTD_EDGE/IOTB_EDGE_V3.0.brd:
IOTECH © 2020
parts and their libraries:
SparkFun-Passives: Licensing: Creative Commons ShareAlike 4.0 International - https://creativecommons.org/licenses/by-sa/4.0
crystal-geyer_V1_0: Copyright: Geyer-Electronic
